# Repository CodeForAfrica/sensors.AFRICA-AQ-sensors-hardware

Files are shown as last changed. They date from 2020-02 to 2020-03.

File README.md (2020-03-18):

# AQ-Sensors-Hardware-Design

These are the design files for the https://sensors.africa/ by https://codeforafrica.org/ AQ kits PCB.

## Tools used

* Autodesk Eagle

* Fusion360

## sensors.AFRICA Stack

1. Firmware - https://github.com/CodeForAfrica/sensors.AFRICA-AQ-sensors-software

2. API - https://github.com/CodeForAfricaLabs/sensors.AFRICA-AQ-api

3. Map - https://github.com/CodeForAfrica/sensors.AFRICA-AQ-map-v2

## Documentation

The Documentation is under development.

## Attribution;

We used the following reference designs in our final design files. We are thankful to the owners for making them open-source.

1. https://github.com/adafruit/Adafruit-FONA-808-Breakout-PCB

2. https://github.com/SeaSlugLabs/Wisol-WSSFM10R2-Sigfox-Breakout/tree/master/Hardware

3. https://github.com/lupyuen/Wisol-WSSFM10R-Sigfox-Breakout

## License

GNU General Public License v3.0

sensors.AFRICA is a citizen-science focused project by Code for Africa that seeks to address data gaps by providing low cost sensors, which people can use to measure and monitor the quality of the air, water, and environment in their communities. This web app seeks to be the public portal through which most users would discover and explore the data and intiative.

Copyright (C) 2019 Code for Africa

This program is free software: you can redistribute it and/or modify
it under the terms of the GNU General Public License as published by
the Free Software Foundation, either version 3 of the License, or
(at your option) any later version.

This program is distributed in the hope that it will be useful,
but WITHOUT ANY WARRANTY; without even the implied warranty of
MERCHANTABILITY or FITNESS FOR A PARTICULAR PURPOSE. See the
GNU General Public License for more details.

You should have received a copy of the GNU General Public License
along with this program. If not, see <https://www.gnu.org/licenses/>

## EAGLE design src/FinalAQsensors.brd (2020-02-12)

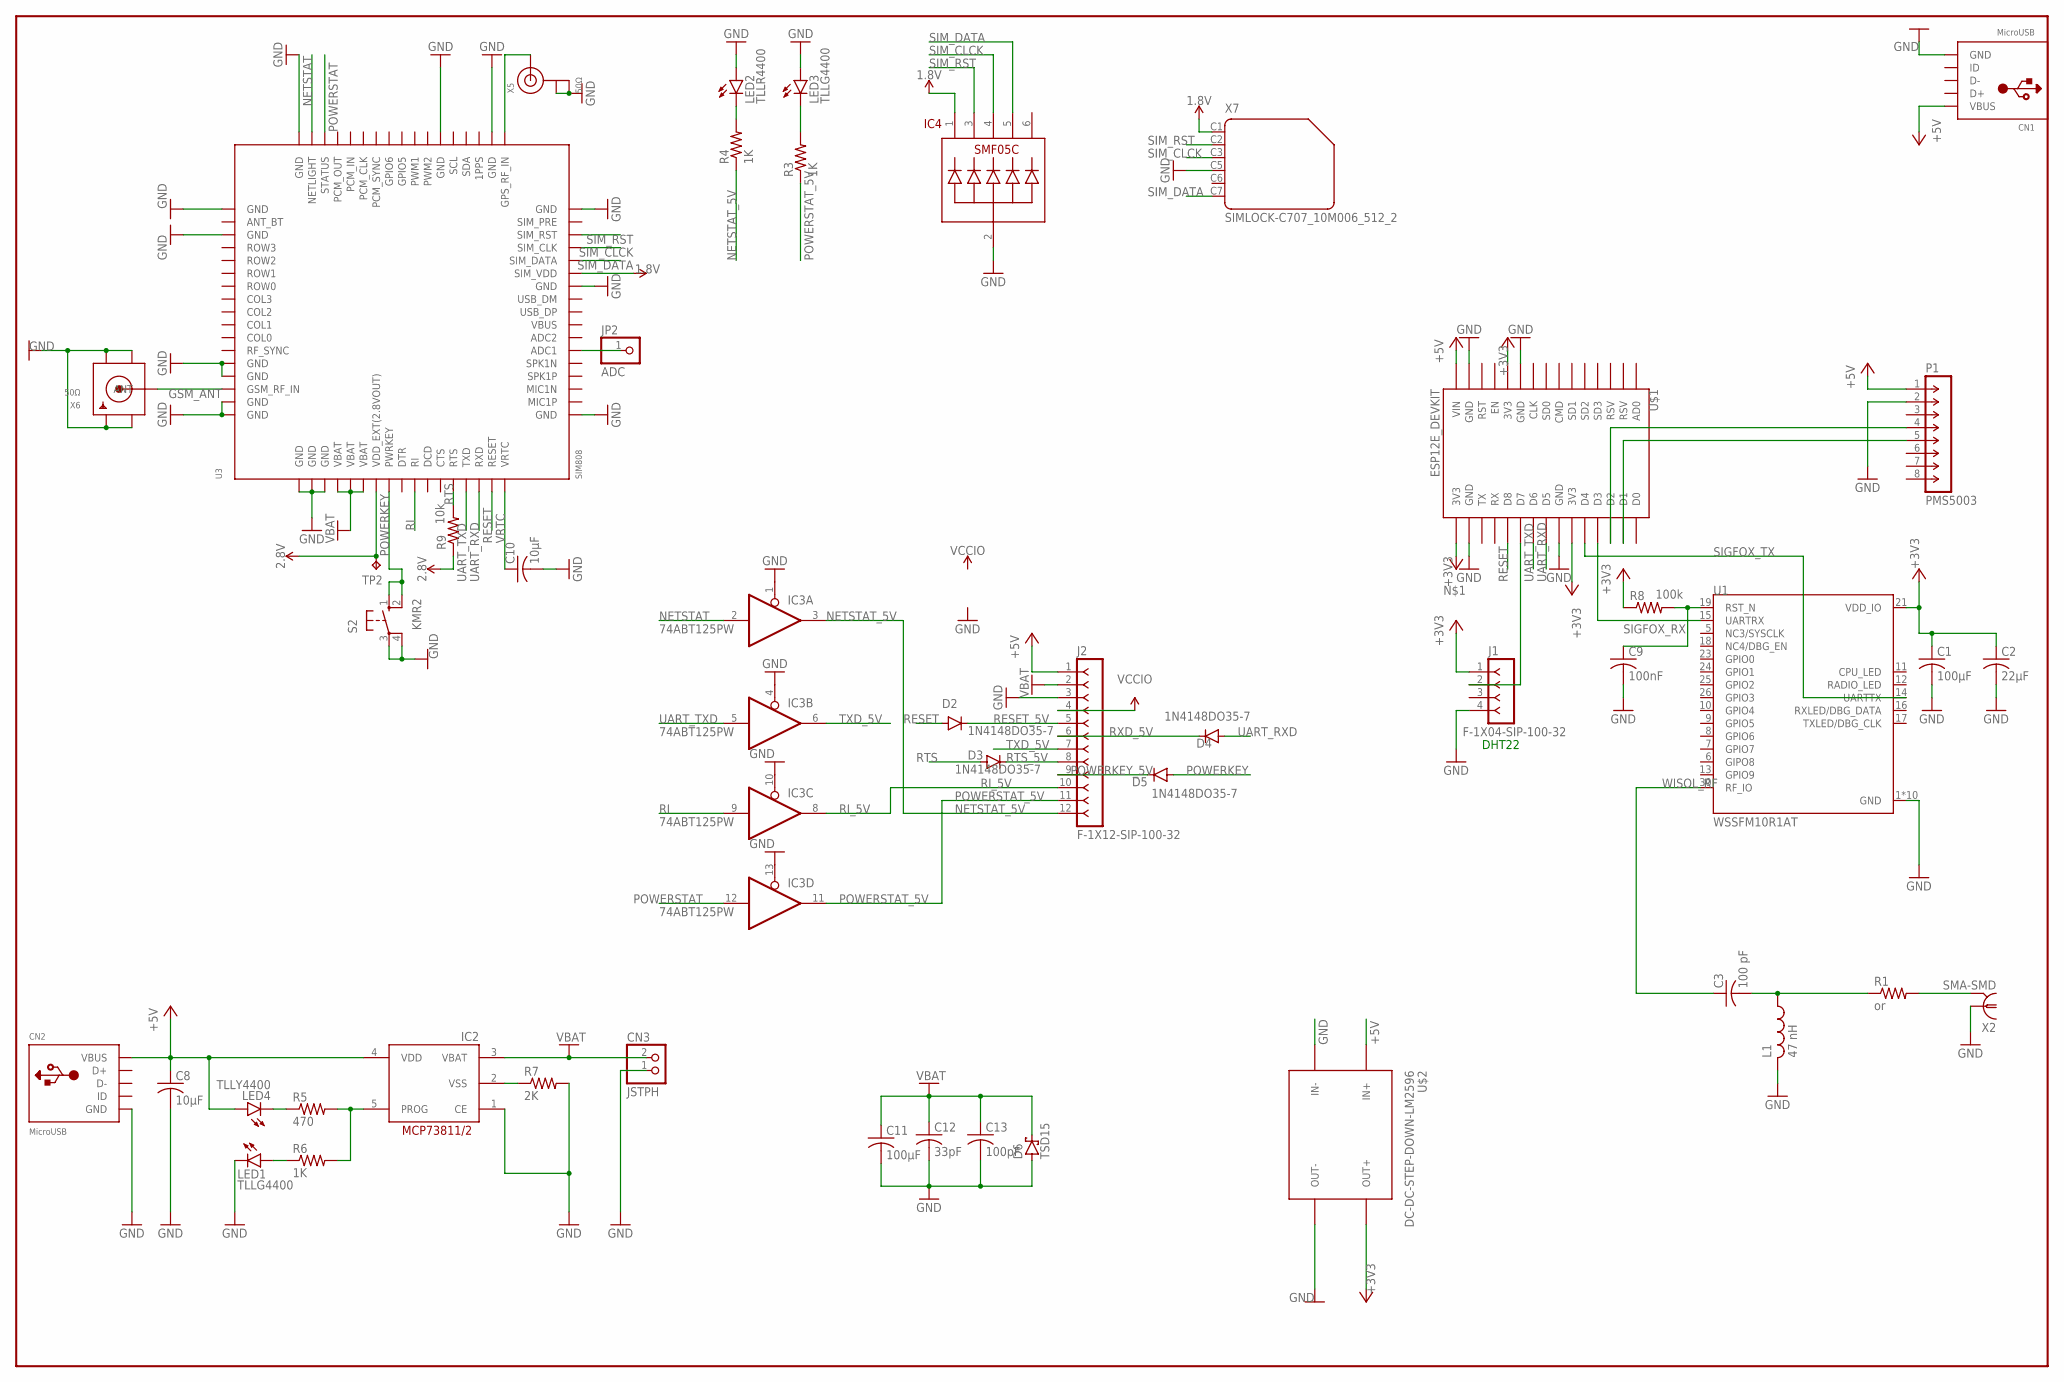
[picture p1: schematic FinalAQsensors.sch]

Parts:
C1: 100μF; C0201
C2: 22μF; C0201
C3: 100 pF; C0201
C8: 10μF; C025-025X050
C9: 100nF; C025-025X050
C10: 10μF; C0402
C11: 100μF; C0402
C12: 33pF; C0402
C13: 100pF; C0402
CN1, CN2: MicroUSB; USB-MINIB
CN3: JSTPH; JST-PH-2-SMT
D2, D3, D4, D5: 1N4148DO35-7; DO35-7
D6: TSD15; CB429-15
IC2: MCP73811/2; SOT23-5L
IC3: 74ABT125PW; TSSOP14
IC4: SMF05C; SC-70-6
J1: F-1X04-SIP-100-32; SIP-100-04-32
J2: F-1X12-SIP-100-32; SIP-100-12-32
JP2: ADC; 1X01M
L1: 47 nH; 0204/7
LED1, LED3: TLLG4400; LED3MM
LED2: TLLR4400; LED3MM
LED4: TLLY4400; LED3MM
P1: PMS5003; SIP-100-08-40
R1: or; 0204/5
R3, R4, R6: 1K; 0204/5
R5: 470; 0204/5
R7: 2K; 0204/5
R8: 100k; 0204/7
R9: 10k; 0204/5
S2: KMR2; B3F/40XX
TP2: TPTP10R; TP10R
U1: WSSFM10R1AT; XCVR_WSSFM10R1AT
U3: SIM808; SIM900_SMT
U$1: ESP12E_DEVKIT
U$2: DC-DC-STEP-DOWN-LM2596
X2: SMA-SMD
X5: 50Ω; U.FL
X6: 50Ω; SMA_EDGELAUNCH_UFL
X7: SIMLOCK-C707_10M006_512_2; C707_10M006_512_2

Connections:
1.8V: IC4.1, U3.P$29 (SIM_VDD), X7.C1 (1)
2.8V: R9.1, TP2.TP, U3.P$7 (VDD_EXT(2.8VOUT))
+3V3: C1.1, C2.1, J1.1, R8.1, U1.21 (VDD_IO), U$1.3V3@0 (3V3), U$1.3V3@1 (3V3), U$1.3V3@2 (3V3), U$2.OUT+
+5V: C8.1, CN1.VBUS, CN2.VBUS, IC2.4 (VDD), J2.1, LED4.A, P1.1, U$1.VIN, U$2.IN+
GND: C1.2, C2.2, C8.2, C9.2, C10.2, C11.2, C12.2, C13.2, CN1.GND, CN2.GND, CN3.1 (2), D6.A, IC2.1 (CE), IC3.1 (OE), IC3.4 (OE), IC3.7 (GND), IC3.10 (OE), IC3.13 (OE), IC4.2, J1.4, J2.3, L1.2, LED1.K (C), LED2.A, LED3.A, P1.2, R7.2, S2.3, S2.4 (P1), U1.1 (GND), U1.2 (GND), U1.3 (GND), U1.4 (GND), U1.20 (GND), U1.22 (GND), U1.27 (GND), U1.28 (GND), U1.29 (GND), U1.31 (GND), U3.P$1 (GND), U3.P$2 (GND), U3.P$3 (GND), U3.P$18 (GND), U3.P$28 (GND), U3.P$34 (GND), U3.P$36 (GND), U3.P$40 (GND), U3.P$51 (GND), U3.P$52 (GND), U3.P$54 (GND), U3.P$64 (GND), U3.P$65 (GND), U3.P$67 (GND), U3.P$68 (GND), U$1.GND@0 (GND), U$1.GND@1 (GND), U$1.GND@2 (GND), U$1.GND@3 (GND), U$2.IN-, U$2.OUT-, X2.1, X5.1 (GND), X5.2 (GND), X6.GND@1 (GND1), X6.GND@2 (GND2), X6.GND@3 (GND3), X6.GND@4 (GND4), X7.C5 (4)
GSM_ANT: U3.P$66 (GSM_RF_IN), X6.P (ANT)
unnamed: J1.2, U$1.D7
unnamed: C9.1, R8.2, U1.19 (RST_N)
unnamed: P1.4, U$1.D2
unnamed: P1.5, U$1.D1
unnamed: C3.2, L1.1, R1.1
unnamed: U3.P$35 (GPS_RF_IN), X5.3 (SIGNAL)
unnamed: R1.2, X2.2@1 (2), X2.2@2 (2), X2.2@3 (2), X2.2@4 (2), X2.2@5 (2), X2.2@6 (2)
unnamed: JP2.1, U3.P$23 (ADC1)
unnamed: LED2.K (C), R4.2
unnamed: LED3.K (C), R3.2
unnamed: LED4.K (C), R5.1
unnamed: IC2.5 (PROG), R5.2, R6.2
unnamed: LED1.A, R6.1
NETSTAT: IC3.2 (I), U3.P$50 (NETLIGHT)
NETSTAT_5V: IC3.3 (O), J2.12, R4.1
POWERKEY: D5.A, S2.1 (S), S2.2 (S1), U3.P$8 (PWRKEY)
POWERKEY_5V: D5.C, J2.9
POWERSTAT: IC3.12 (I), U3.P$49 (STATUS)
POWERSTAT_5V: IC3.11 (O), J2.11, R3.1
RESET: D2.A, U3.P$16 (RESET), U$1.D8
RESET_5V: D2.C, J2.5
RI: IC3.9 (I), U3.P$10 (RI)
RI_5V: IC3.8 (O), J2.10
RTS: D3.A, R9.2, U3.P$13 (RTS)
RTS_5V: D3.C, J2.8
RXD_5V: D4.C, J2.6
SIGFOX_RX: U1.15 (UARTRX), U$1.D3
SIGFOX_TX: U1.14 (UARTTX), U$1.D4
SIM_CLCK: IC4.4, U3.P$31 (SIM_CLK), X7.C3 (3)
SIM_DATA: IC4.5, U3.P$30 (SIM_DATA), X7.C7 (6)
SIM_RST: IC4.3, U3.P$32 (SIM_RST), X7.C2 (2)
TXD_5V: IC3.6 (O), J2.7
UART_RXD: D4.A, U3.P$15 (RXD), U$1.D5
UART_TXD: IC3.5 (I), U3.P$14 (TXD), U$1.D6
VBAT: C11.1, C12.1, C13.1, CN3.2 (1), D6.C, IC2.3 (VBAT), J2.2, U3.P$4 (VBAT), U3.P$5 (VBAT), U3.P$6 (VBAT)
VBUS: U3.P$25 (VBUS)
VCC: IC3.14 (VCC)
VCCIO: J2.4
VRTC: C10.1, U3.P$17 (VRTC)
VSS: IC2.2 (VSS), R7.1
WISOL_RF: C3.1, U1.30 (RF_IO)

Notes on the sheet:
DHT22

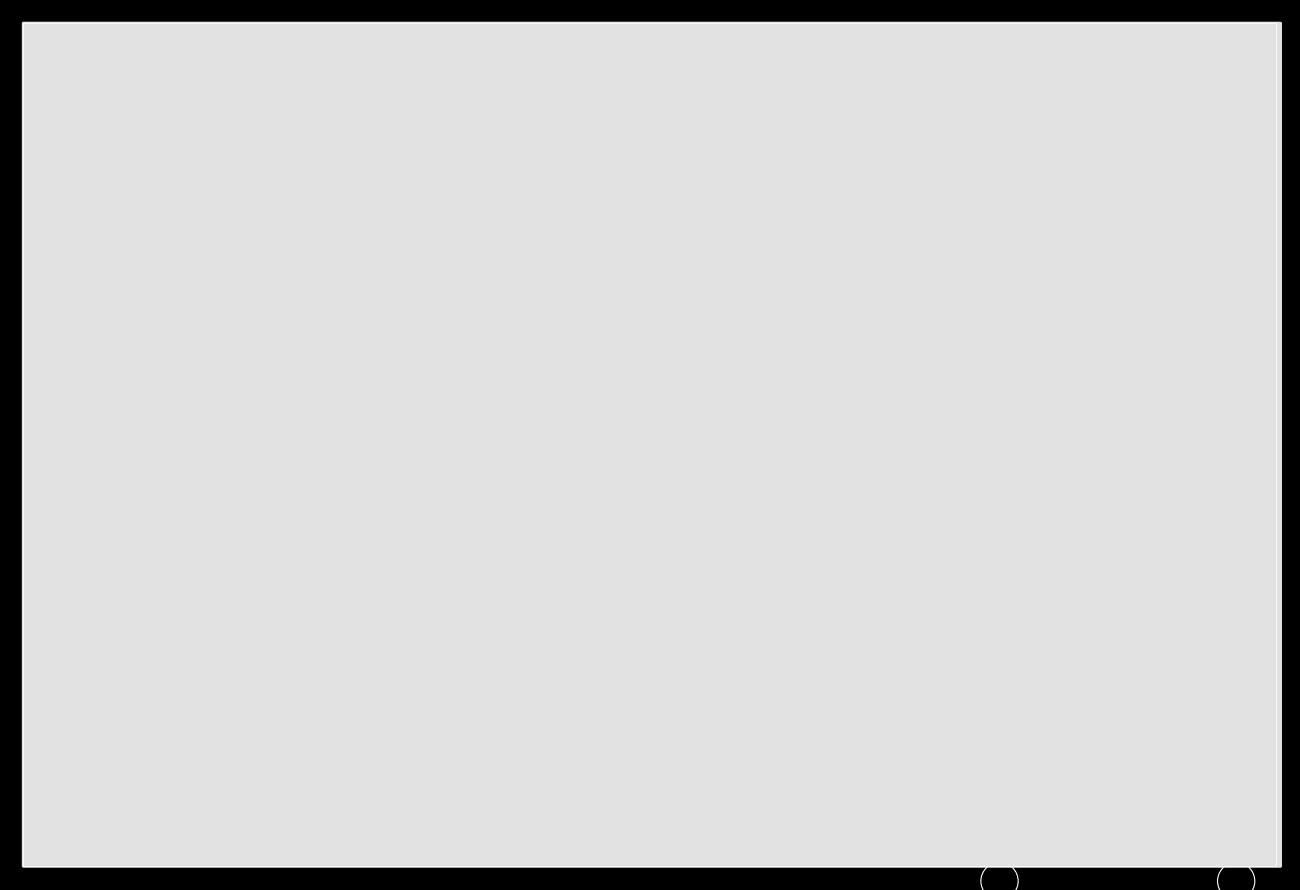
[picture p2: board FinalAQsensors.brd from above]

Board: 2 copper layers, 107.6 x 72.4 mm, 47 parts (0 on the bottom side), 44 nets.

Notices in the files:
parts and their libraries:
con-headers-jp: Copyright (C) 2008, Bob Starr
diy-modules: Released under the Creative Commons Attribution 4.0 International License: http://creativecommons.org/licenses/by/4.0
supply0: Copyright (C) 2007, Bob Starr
